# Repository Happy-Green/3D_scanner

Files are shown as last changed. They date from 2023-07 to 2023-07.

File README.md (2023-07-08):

## Hierarchia folderów:
**user_lib** - aplikacja skanera

**vl53l1x_driver** - sterownik do VL53L1X

**pwmServoDriver** - sterownik do serw 360

**CAD_files** - Modele części składowych urządzenia

# Projekt z przedmiotu SWIS

Celem projektu było stworzenie modelu koncepcyjnego skanera objektów trójwymiarowych z wykorzystaniem czujnika odległości ToF VL53L1X rodziny ST. W przypadku projektu posłużono się płytą rozszerzeniową 53L1A1 do obsługi 3 czujników ToF.

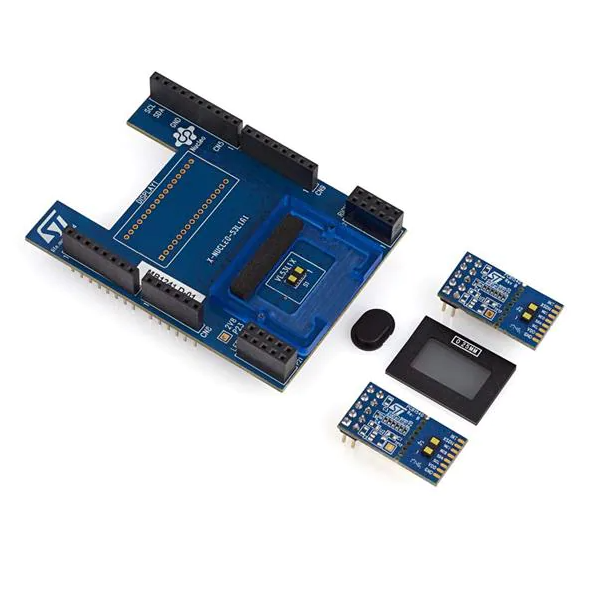
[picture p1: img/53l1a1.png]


W ramach projektu skupiono się na stworzeniu koncepcji samego skanera i jego konstrukcji, napisaniu sterowników do obsługi dwóch serw oraz możliwości obsługi trzech czujników ToF oraz napisaniu programu do operowania urządzeniem i wczytywania danych. Do wizualizacji chmury punktów obiektu w przestrzeni wykorzystano program CloudCompare (https://github.com/CloudCompare).

#  Opis urządzenia

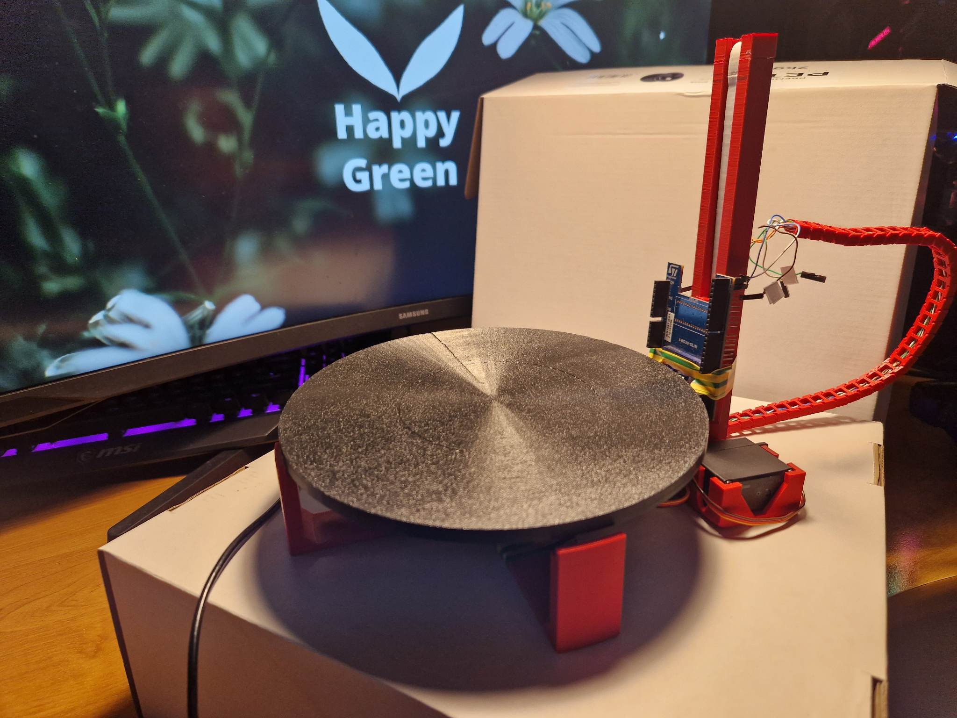
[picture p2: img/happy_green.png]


#  Sterowniki
## VL53L1X

Na stronie https://elixir.bootlin.com/ można znaleźć sterownik do VL53L0X. Niestety różni się mapą rejestrów z VL53L1X. Zdecydowano odwołać się do przykładowego sterownika typu misc zaproponowanego przez STMicroelectronics. (https://www.st.com/en/embedded-software/stsw-img013.html) Jest to przykład sterownika, który nie obsługuje samego urządzenia, tylko jego PIN przerwaniowy, na stałe wpisany przez użytkownika. W naszym przypadku został stworzony sterownik typu character device tworzony jako `/dev/`, komunikujący się za pomocą i2c. Kolejnym ważnym elementem którego zabrakło w przykładzie ST był brak obsługi urządzenia (otwieranie, wczytywanie i zapisywanie), bądź obsługa kilku urządzeń tej samej klasy. Dodano więc elementy nadawania numerów MAJOR i MINOR dla urządzeń oraz zaimplementowano prostą obsługę inicjalizacji urządzenia, jego otwierania i zwalniania, bądź obsługi read/write i przerwań.

## servoDriver

Należało się skupić nad możliwością konfiguracji serw z poziomu drzewa urządzeń. Taka koncepcja znacznie bardziej ujednolica konfigurację serw PWM, szczególnie w przypadku wykorzystania różnych rodzajów tego elementu, gdyż każdy z nich może mieć inny poziom wyzwalania kierunku oraz szybkości obrotu. W tym przypadku również odwołano się do sterownika urządzeń typu char, generowanego jako urządzenie `/proc/`. Komunikacja między tego typu urządzeniami może być łatwo zaimplementowana przez polecenia `bash`. Stworzono 3 tryby operowania: SLOW(1), FAST(2) oraz STOP(0). Serwa odpowiednio się obracają dla tych poleceń, na podstawie otrzymywanych w funkcji probe parametrów z device tree. Sterownik obecnie jest zdefiniowany dla dwóch instancji serw.

## Aplikacja

W aplikacji posłużono się dostarczanym przez ST API. Zdefiniowaliśmy swoje funkcje (nadpisaliśmy) specyficzne dla platformy (Linux), żeby api wywoływało inicjalizację VL53L1X oraz obsługiwało komunikację, bądź zgłoszenia urządzenia przez przerwania poprzez kernel. Następnie osobno zdefiniowano obsługę serw za pomocą poleceń `bash`, wywoływanych w aplikacji. Kolejność obsługi urządzeń została rozwiązana za pomocą wykorzystania mutexa i wątku.

### Sposób działania skanera (aplikacji)
1. Inicjalizowane są maksymalnie 3 czujniki VL53L1X. (W projekcie używamy jednego, ze względu na zbyt duże odstępy między czujnikami na płytce 53L1A1).
2. Tworzony jest wątek obsłi serw (`handler`).
3. Wykonywany jest wstępny obrót stolika skanera (Zajmowany i zwalniany mutex, VL53L1X czeka).
4. Wykonywany jest wstępny róch do góry (Zajmowany i zwalniany mutex, VL53L1X czeka).

W kolejnych itercjach jest powtarzany algorytm:

1. VL53L1X zajmuje mutex i razem z ruchem obrotu stolika skanera wykonuje się pomiar (80 pomiarów na obrót).
2. Gdy stolik kończy obrót wywoływane jest polecenie przesunięcia serwa z czujnikiem VL53L1X do góry (jak mutex nie jest zwolniony, to nie przesuwa, czeka).
3. Jak tylko skończy się ostatni pomiar VL53L1X, serwo ruchu do góry przejmuje mutex, a VL53L1X czeka na ten mutex.
4. Servo ruchu do góry zwalnia mutex, powtarza się punkt 1.

### Algorytm przetwarzania odległości na punkty w przestrzeni
W ramach algorytmu do wyznaczenia położenia wykorzystano macierz rotacji. Przekazujemy zmierzony dystans (r) z czujnika oraz kąt obrotu (θ). Używając macierzy rotacji względem osi Z:
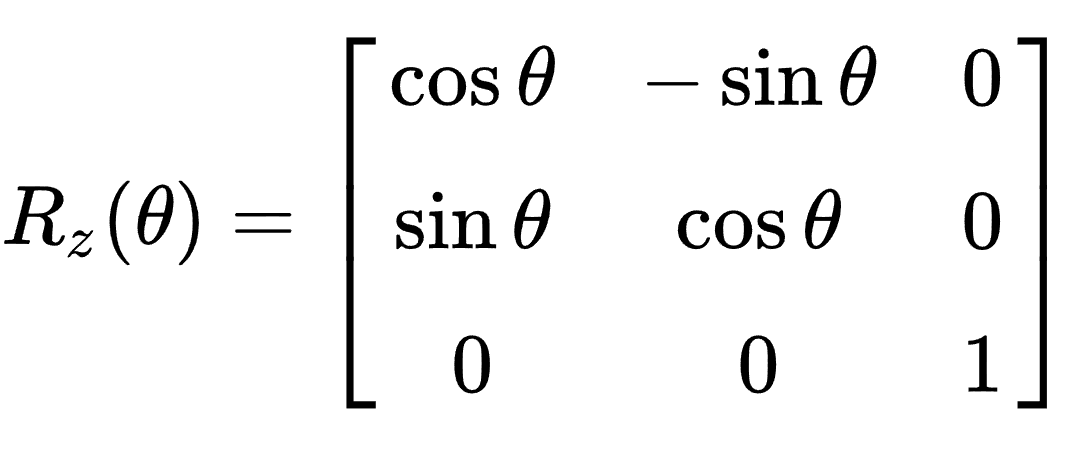
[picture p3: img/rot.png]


otrzymujemy współrzędne X i Y. Z zaś wyznaczamy jako stosunek całej drogi do góry przez liczbę przesunięć czujnika razy numer przesunięcia.

# Wynik
Otrzymano następujący zeskanowany kształt.

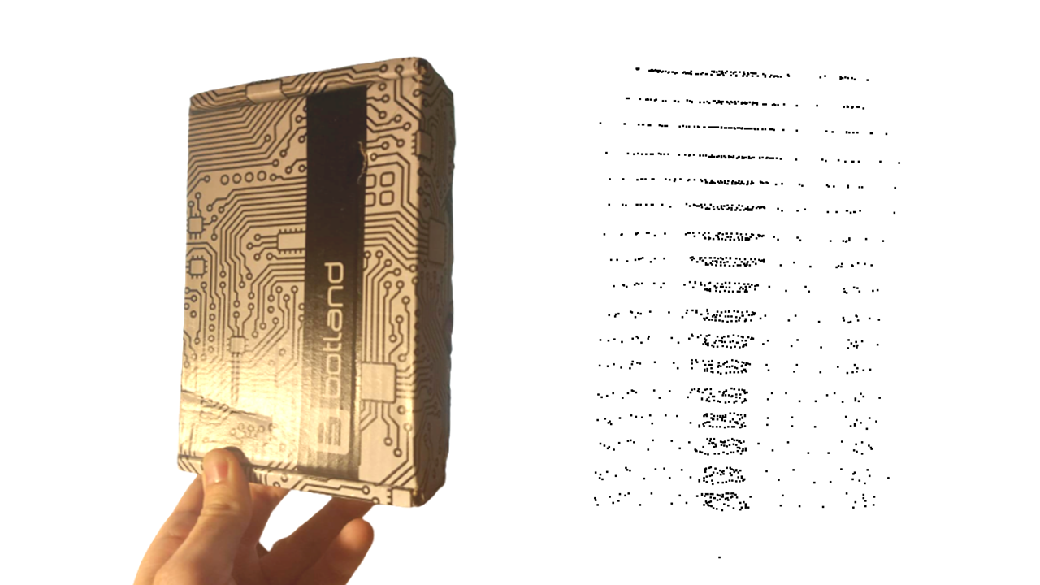
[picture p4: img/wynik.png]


Widać wyraźnie, że z powodu dużego przesunięcia w osi Z jest gubiona duża liczba próbek, aczkolwiek wiązałoby się to z bardzo długim czasem pomiaru. Aczkolwiek można zauważyć podobieństwo kształtu. Jakość pomiaru można też spróbować usprawnić zwiększając rozdzielczość matrycy SPAD czy próbując użyć kilku czujników VL53L1X czy też próbując zwiększyć próbkowanie.

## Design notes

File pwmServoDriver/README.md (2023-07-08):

`make`

`sudo dtoverlay servooverlay.dtbo`

`sudo insmod servoDriver.ko`

`sudo dmesg | tail`

`sudo rmmod servoDriver.ko`

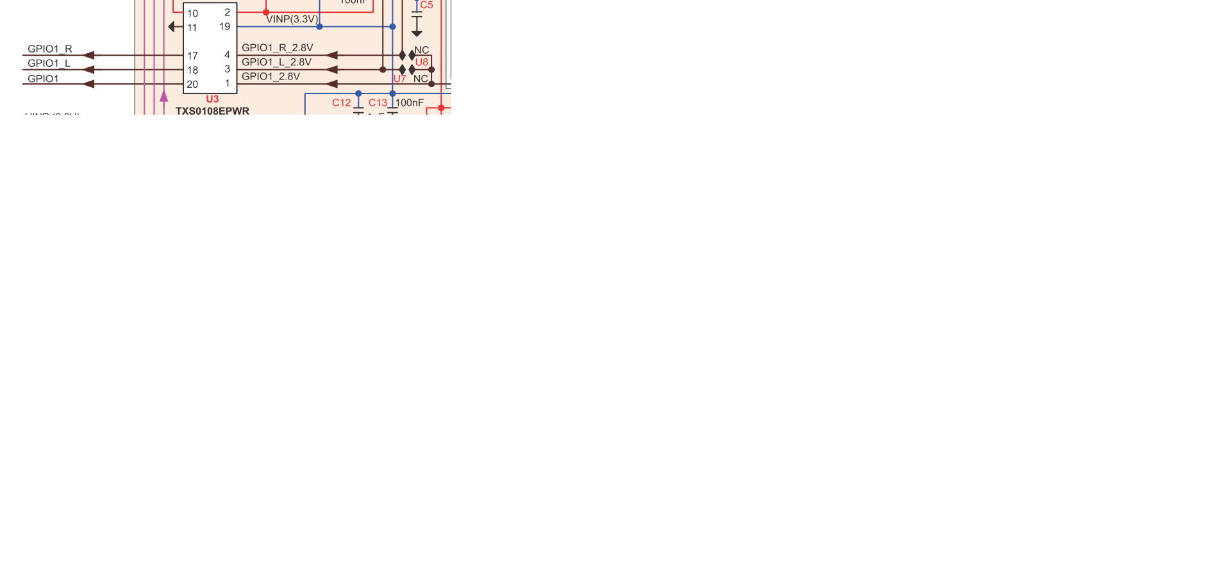
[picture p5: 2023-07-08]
img/U7U8.png

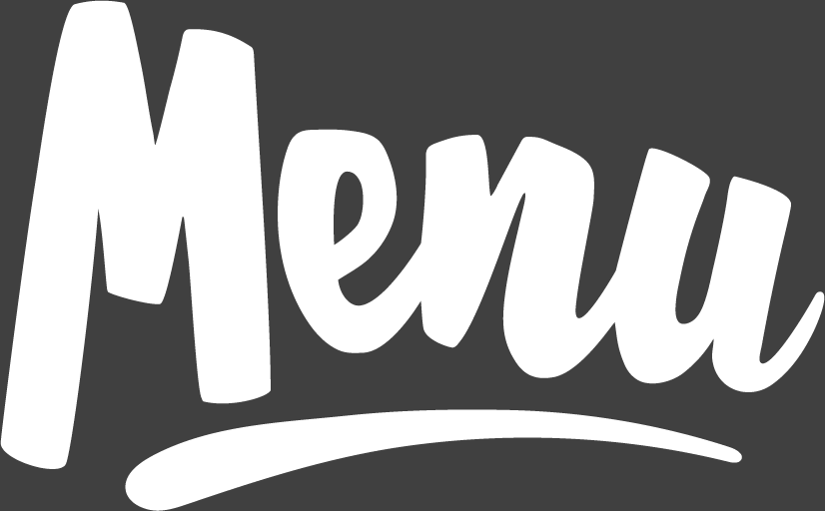
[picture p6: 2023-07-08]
GUI/obrazek.jpg

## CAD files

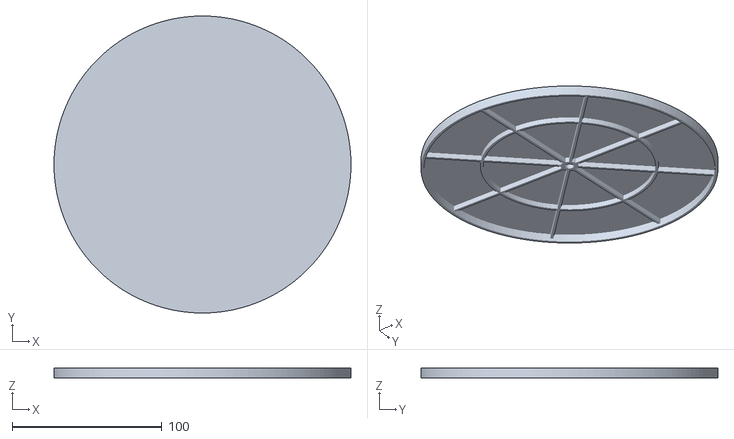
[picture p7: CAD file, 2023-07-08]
CAD_files/talerz.stl
198.0 x 198.0 x 6.60

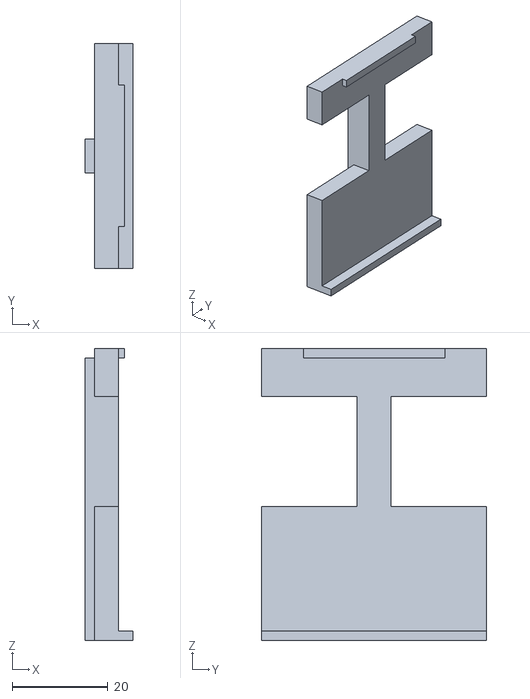
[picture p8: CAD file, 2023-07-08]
CAD_files/glowica.stl
10.0 x 47.0 x 61.0

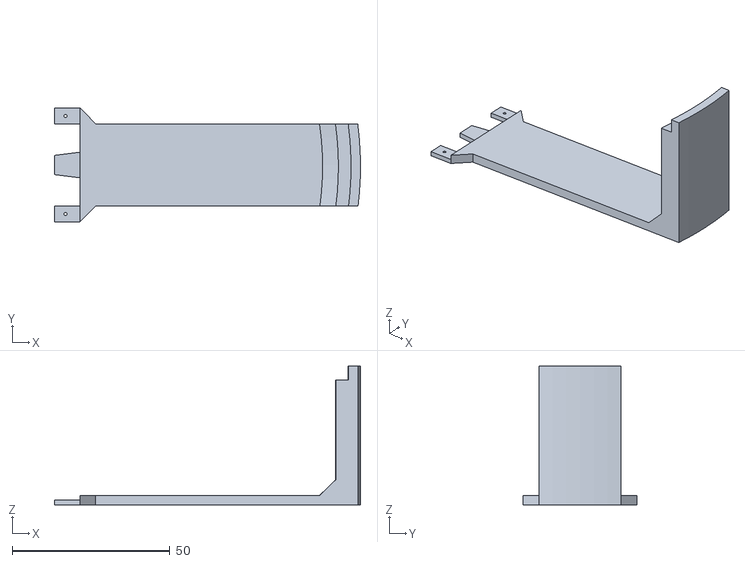
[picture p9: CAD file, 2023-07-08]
CAD_files/Noga_Skaneru_1z2.stl
96.9 x 36.1 x 44.0

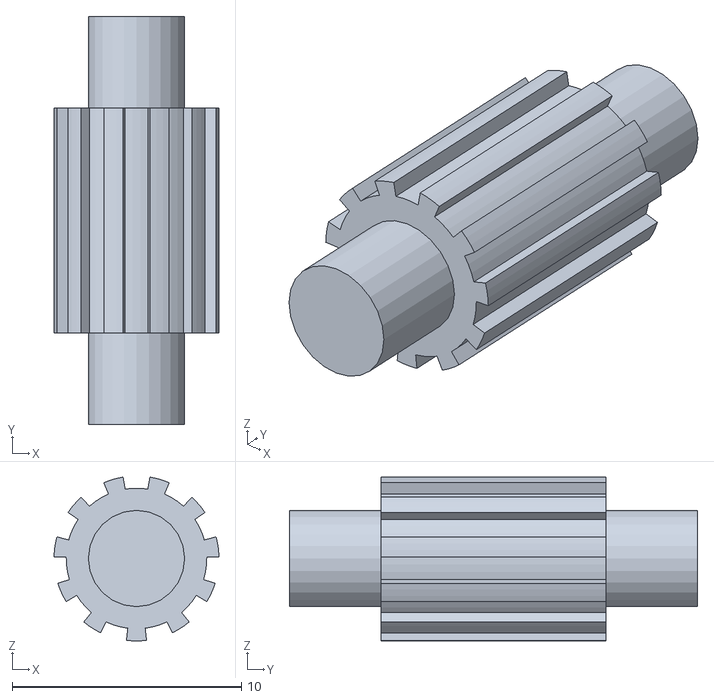
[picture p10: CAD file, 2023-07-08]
CAD_files/bieg_górny.stl
7.20 x 17.8 x 7.15

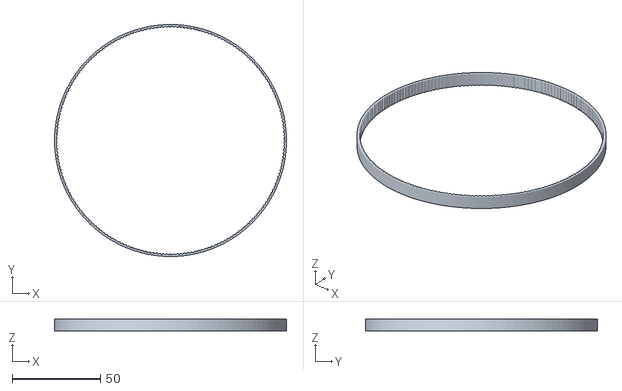
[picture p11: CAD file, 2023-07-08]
CAD_files/pas_zebaty.stl
131.4 x 131.4 x 7.00

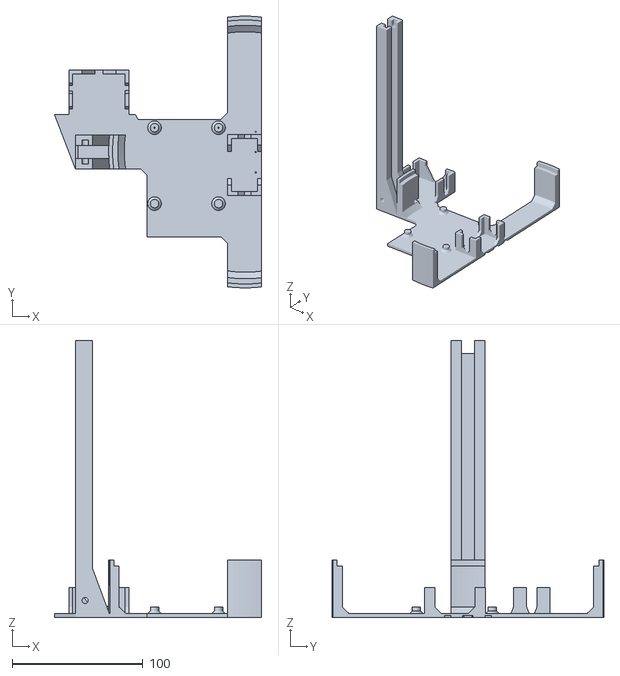
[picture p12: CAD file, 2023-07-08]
CAD_files/głowny_szkielet.stl
158.7 x 208.0 x 212.0

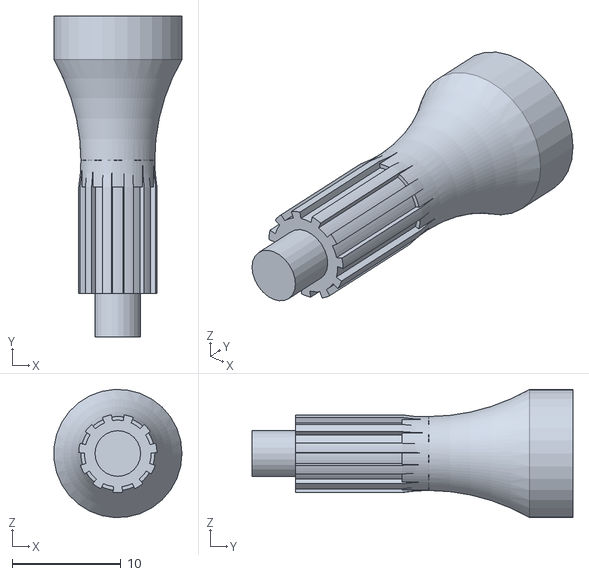
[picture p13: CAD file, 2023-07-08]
CAD_files/wał_dolny.stl
11.8 x 29.5 x 11.8

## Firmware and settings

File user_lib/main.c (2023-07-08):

/**
 *
 * App 3D scanner using VL53L1X and AR360HB3 360 degree servo multi-device drivers for SWIS course (WEITI PW).
 * Based on https://www.st.com/en/embedded-software/stsw-img013.html VL53L1X ULD
 *
 * @authors Albert Bogdanovic, Konrad Kacper Domian (WEITI PW)
 * @copyright (C) 2023 by Albert Bogdanovic, Konrad Domian
 * License GPL v2
 * konrad.domian.stud<at>pw.edu.pl | konrad.kacper.domian@gmail.com
 * albert.bogdanovic.stud<at>pw.edu.pl | albertbog@gmail.com
 */

/* Includes ------------------------------------------------------------------*/
#include <malloc.h>
#include <stdio.h>
#include <errno.h>
#include <string.h>
#include <stdio.h>
#include <stdlib.h>
#include <unistd.h>
#include <linux/i2c-dev.h>
#include <sys/ioctl.h>
#include <sys/types.h>
#include <sys/stat.h>
#include <fcntl.h>
#include <sys/time.h>
#include <string.h>
#include <sys/types.h>
#include <sys/socket.h>
#include <netinet/in.h>
#include <signal.h>
#include <stdint.h>
#include <sys/types.h>
#include <sys/stat.h>
#include <fcntl.h>
#include <pthread.h>
#include <stdio.h>
#include <time.h>

#include "VL53L1X_api.h"
#include "VL53L1X_calibration.h"
#include "vl53l1_platform.h"
#include "scanner_func.h"
/* Defines ------------------------------------------------------------------*/

static uint8_t stop_app = 0;
static uint8_t num_of_move_z = 0;
static uint8_t num_of_angle_points = 0;

uint16_t Dev;
pthread_mutex_t mut_lock;

static void *servo_handler(void *arg)
{
	pthread_mutex_lock(&mut_lock);
	move_xy();
	pthread_mutex_unlock(&mut_lock);

	for (int i = 0; i < NUM_OF_MAX_Z_MOVEMENTS; i++)
	{
		pthread_mutex_lock(&mut_lock);
		move_z();
		pthread_mutex_unlock(&mut_lock);
		num_of_move_z++;
		num_of_angle_points = 0;
		move_xy();
	}
	pthread_mutex_lock(&mut_lock);
	move_z_down();
	pthread_mutex_unlock(&mut_lock);
	stop_app = 1;

	return 0;
}

/* main  --------------------------------------------------------------------*/

int main(int argc, char **argv)
{
	int status;
	uint8_t byteData, sensorState = 0;
	uint16_t wordData;
	VL53L1X_Result_t Results;
	uint8_t first_range = 1;
	pthread_t servo_thread;
	FILE *fp;

	float distance_from_lidar_mm, r_oz_degree, h;
	float *p;

	VL53L1X_UltraLite_Linux_I2C_Init(0, 0, 0); // overwritten VL53L1 API function to initialize 3 sensors
	printf("Init VL53L1X\n");

	for (int ToFSensor = 0; ToFSensor < NUM_OF_DEVICES; ToFSensor++)
	{
		switch (ToFSensor)
		{
		case CENTER_DEVICE:
			Dev = CENTER_DEVICE;
			break;
		case LEFT_DEVICE:
			Dev = LEFT_DEVICE;
			break;
		case RIGHT_DEVICE:
			Dev = RIGHT_DEVICE;
			break;
		}
		status = VL53L1_RdByte(Dev, 0x010F, &byteData);
		printf("VL53L1X Model_ID: %X\n", byteData);
		status += VL53L1_RdByte(Dev, 0x0110, &byteData);
		printf("VL53L1X Module_Type: %X\n", byteData);
		status += VL53L1_RdWord(Dev, 0x010F, &wordData);
		printf("VL53L1X: %X\n", wordData);
		while (sensorState == 0)
		{
			status += VL53L1X_BootState(Dev, &sensorState);
			VL53L1_WaitMs(Dev, 2);
		}
		printf("Chip booted\n");

		status = VL53L1X_SensorInit(Dev);
		/* status += VL53L1X_SetInterruptPolarity(Dev, 0); */
		status += VL53L1X_SetDistanceMode(Dev, 1); /* 1=short, 2=long */
		status += VL53L1X_SetTimingBudgetInMs(Dev, 100);
		status += VL53L1X_SetInterMeasurementInMs(Dev, 100);
		if (status)
		{
			printf("Vl53L1X_%d failed, err = %d\n", Dev, status);
			return -1;
		}
	}

	status += pthread_mutex_init(&mut_lock, NULL);
	status += pthread_create(&servo_thread, NULL, servo_handler, NULL);
	if (status)
	{
		printf("error creating thread\n");
	}

	fp = fopen("3d_data.txt", "w");
	/* read and display data loop */
	while (1)
	{
		if (stop_app)
			break;
		for (int ToFSensor = 0; ToFSensor < NUM_OF_DEVICES; ToFSensor++)
		{
			switch (ToFSensor)
			{
			case CENTER_DEVICE:
				Dev = CENTER_DEVICE;
				break;
			case LEFT_DEVICE:
				Dev = LEFT_DEVICE;
				break;
			case RIGHT_DEVICE:
				Dev = CENTER_DEVICE;
				break;
			}
			pthread_mutex_lock(&mut_lock);

#if defined(POLLING)
			uint8_t dataReady = 0;

			while (dataReady == 0)
			{
				status = VL53L1X_CheckForDataReady(Dev, &dataReady);
				usleep(1);
			}
#else
			status += VL53L1X_StartRanging(Dev);
			status = VL53L1X_UltraLite_WaitForInterrupt(Dev, ST_TOF_IOCTL_WFI);
			if (status)
			{
				printf("ST_TOF_IOCTL_WFI failed, err = %d\n", status);
				return -1;
			}
#endif
			/* Get the data the new way */
			status += VL53L1X_GetResult(Dev, &Results);
			if (status != 0)
			{
				printf("error while getting data\n");
			}

			// printf("Status = %2d, dist = %5d, Ambient = %2d, Signal = %5d, #ofSpads = %5d\n",
			// 	Results.Status, Results.Distance, Results.Ambient,
			// 						Results.SigPerSPAD, Results.NumSPADs);

			printf("VL53L1X_%d Status = %2d, dist = %5d\n", Dev, Results.Status, Results.Distance);

			distance_from_lidar_mm = Results.Distance;
			r_oz_degree = num_of_angle_points * 360 / NUM_OF_POINTS_PER_SCAN;
			num_of_angle_points++;
			h = num_of_move_z * MAX_Z_DISTANCE_MM / NUM_OF_MAX_Z_MOVEMENTS;

			p = calc_3D_pos(distance_from_lidar_mm, r_oz_degree, h);
			if (p != NULL)
			{
				fprintf(fp, "%f, %f, %f\n", p[0], p[1], p[2]);
				printf("X: %f, Y: %f, Z: %f\n", p[0], p[1], p[2]);
			}
			free(p);

			/* trigger next ranging */
			status += VL53L1X_ClearInterrupt(Dev);
			if (first_range)
			{
				/* very first measurement shall be ignored
				 * thus requires twice call
				 */
				status += VL53L1X_ClearInterrupt(Dev);
				first_range = 0;
			}
			pthread_mutex_unlock(&mut_lock);
		}
	}
	fclose(fp);
	return 0;
}

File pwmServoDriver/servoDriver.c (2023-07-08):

/**
 *
 * Linux driver for AR360HB3 360 degree servo
 *
 * Significantly based on multiple drivers included in
 * sources of Linux and driver examples by prof. Wojciech Zabołotny (WEITI PW) | https://github.com/wzab
 * @authors Konrad Kacper Domian, Albert Bogdanovic (WEITI PW)
 * @copyright (C) 2023 by Konrad Domian & Albert Bogdanovic
 * License GPL v2
 * konrad.domian.stud<at>pw.edu.pl | konrad.kacper.domian@gmail.com
 * albert.bogdanovic.stud<at>pw.edu.pl
 */

/**Reads libs*/
#include <linux/module.h>
#include <linux/init.h>
#include <linux/mod_devicetable.h>
#include <linux/property.h>
#include <linux/platform_device.h>
#include <linux/of_device.h>
#include <linux/pwm.h>
#include <linux/proc_fs.h>
#include <linux/string.h>

/**Meta Information*/
MODULE_AUTHOR("Konrad Domian & Albert Bogdanovic");
MODULE_DESCRIPTION("PWM 360 degree Servo driver with irq when servo starts");
MODULE_LICENSE("GPL v2");
/**Meta Information*/

/**
 * @todo move to h file
 */
#define MAX_DEVICES 2

#define IS_DIGIT(char) \
    (char - '0' >= 0 && char - '0' <= 9)

#define MAP_MOVE(str, val)             \
    if (strcmp(inputString, str) == 0) \
    return val

enum MOVE
{
    STOP = 0,
    SLOW = 1,
    FAST = 2
};

enum MOVE mapStringToMove(const char *inputString)
{
    MAP_MOVE("STOP", STOP);
    MAP_MOVE("SLOW", SLOW);
    MAP_MOVE("FAST", FAST);

    return -1;
}

enum LABELS
{
    servo_pwm_xy = 0,
    servo_pwm_z = 1
};

enum LABELS mapStringToLabels(const char *inputString)
{
    MAP_MOVE("servo_pwm_xy", servo_pwm_xy);
    MAP_MOVE("servo_pwm_z", servo_pwm_z);

    return -1;
}
/**MOVE TO .h FILE*/

/**Declate the probe and remove fun*/
static int dt_probe(struct platform_device *pdev);
static int dt_remove(struct platform_device *pdev);

static struct of_device_id servo_driver_ids[] = {
    {
        .compatible = "happygreen, servo",
    },
    {/* sentinel */}};
MODULE_DEVICE_TABLE(of, servo_driver_ids);

static struct platform_driver servo_driver = {
    .probe = dt_probe,
    .remove = dt_remove,
    .driver = {
        .name = "servo_device_driver",
        .of_match_table = servo_driver_ids,
    },
};

struct servoDriver
{
    struct pwm_device *pwm;
    const char *label;
    unsigned int pwm_channel, pwm_freq;
    unsigned int pwm_duty_cycle_stop, pwm_duty_cycle_slow_move, pwm_duty_cycle_fast_move;
    struct proc_dir_entry *proc_file;
};

static struct servoDriver devices[MAX_DEVICES];
/**
 * @brief Write data to buffer
 */
static ssize_t my_write(struct file *File, const char *user_buffer, size_t count, loff_t *offs)
{
    int move = 0;
    char temp_str[4];
    static struct servoDriver device;
    printk("write_servo - Now I am in the my_write func\n");
    if (IS_DIGIT(user_buffer[0]))
        move = user_buffer[0] - '0';
    else
    {
        strncpy(temp_str, user_buffer, 4);
        move = mapStringToMove(temp_str);
    }

    switch (mapStringToLabels(File->f_path.dentry->d_name.name))
    {
    case 0:
        device = devices[0];
        break;
    case 1:
        device = devices[1];
        break;
    default:
        printk("write_servo - Error unkown device label\n");
        break;
    }

    switch (move)
    {
    case 0:
        printk("write_servo - Stop servo\n");
        pwm_config(device.pwm, device.pwm_duty_cycle_stop, device.pwm_freq);
        break;
    case 1:
        printk("write_servo - Move Slow servo\n");
        pwm_config(device.pwm, device.pwm_duty_cycle_slow_move, device.pwm_freq);
        break;
    case 2:
        printk("write_servo - Move Fast servo\n");
        pwm_config(device.pwm, device.pwm_duty_cycle_fast_move, device.pwm_freq);
        break;

    default:
        printk("write_servo - Not corrent data\n");
        break;
    }

    return count;
}

static struct proc_ops fops = {
    .proc_write = my_write,
};

/**
 * @brief This fun is called, when the module is loading into the kernel
 */
static int dt_probe(struct platform_device *pdev)
{
    struct device *dev = &pdev->dev;
    const char *label, *temp_str;
    int ret;
    unsigned int pwm_channel, pwm_freq;
    unsigned int pwm_duty_cycle_stop, pwm_duty_cycle_slow_move, pwm_duty_cycle_fast_move, servo_move;
    static struct servoDriver device;

    printk("dt_servo - Now I am in the probe fun\n");

    // check for device properies
    if (!device_property_present(dev, "label"))
    {
        printk("dt_servo - Error! Device propoerty 'label' not found!\n");
        return -1;
    }
    if (!device_property_present(dev, "pwm_channel"))
    {
        printk("dt_servo - Error! Device propoerty 'pwm_channel' not found!\n");
        return -1;
    }
    if (!device_property_present(dev, "pwm_freq"))
    {
        printk("dt_servo - Error! Device propoerty 'pwm_freq' not found!\n");
        return -1;
    }
    if (!device_property_present(dev, "pwm_duty_cycle_stop"))
    {
        printk("dt_servo - Error! Device propoerty 'pwm_duty_cycle_stop' not found!\n");
        return -1;
    }
    if (!device_property_present(dev, "pwm_duty_cycle_slow_move"))
    {
        printk("dt_servo - Error! Device propoerty 'pwm_duty_cycle_slow_move' not found!\n");
        return -1;
    }
    if (!device_property_present(dev, "pwm_duty_cycle_fast_move"))
    {
        printk("dt_servo - Error! Device propoerty 'pwm_duty_cycle_fast_move' not found!\n");
        return -1;
    }
    if (!device_property_present(dev, "servo_move"))
    {
        printk("dt_servo - Error! Device propoerty 'servo_move' not found!\n");
        return -1;
    }
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
